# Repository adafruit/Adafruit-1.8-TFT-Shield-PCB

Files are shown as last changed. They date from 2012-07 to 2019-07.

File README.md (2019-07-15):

## Adafruit 1.8" 18-bit Color TFT Shield w/microSD and Joystick PCB

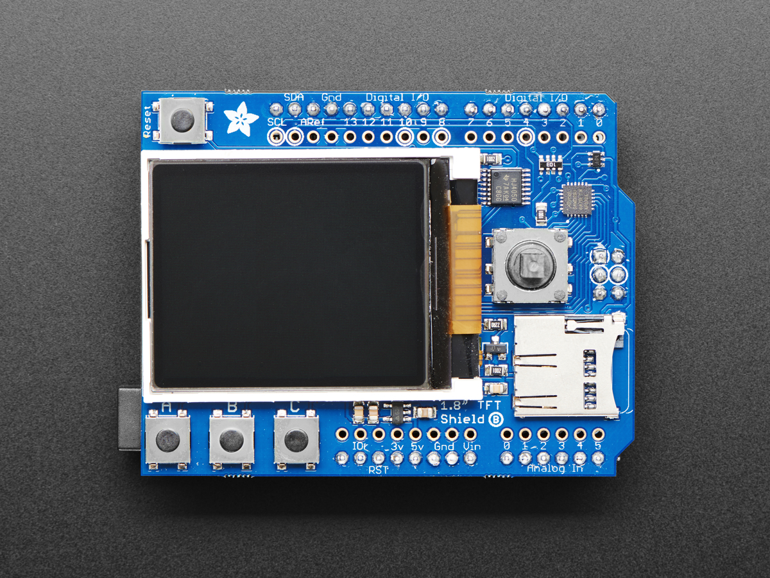
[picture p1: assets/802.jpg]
<a href="http://www.adafruit.com/products/802"><br/>
Click here to purchase one from the Adafruit shop</a>

PCB files for the Adafruit 1.8" 18-bit Color TFT Shield. Format is EagleCAD schematic and board layout
* https://www.adafruit.com/product/802

### Description

This lovely little shield is the best way to add a small, colorful and bright display to any project. We took our popular 1.8" TFT breakout board and remixed it into an Arduino shield complete with microSD card slot and a 5-way joystick navigation switch and three selection buttons! Since the display uses only 4 pins to communicate and has its own pixel-addressable frame buffer, it can be used easily to add a display & interface without exhausting the memory or pins.

New! We've updated this shield to be 'Arduino R3' format compatible so you can now use it with any and all Arduinos or Metros - including the Metro M0 or M4, Arduino Mega, Zero, etc. We also use Adafruit seesaw for the TFT backlight, TFT reset, and button inputs - you can query the buttons and joystick over I2C now, so only 2 pins are needed to communicate with all 8 switches.

The 1.8" display has 128x160 color pixels. Unlike the low cost "Nokia 6110" and similar LCD displays, which are CSTN type and thus have poor color and slow refresh, this display is a true TFT! The TFT driver (ST7735R) can display full 18-bit color (262,144 shades!).

The shield has the TFT display soldered on (it uses a delicate flex-circuit connector) as well as a ultra-low-dropout 3.3V regulator and a 3/5V level shifter so its safe to use with 3V or 5V Arduino compatibles. We also had some space left over so we placed a microSD card holder (so you can easily load full color bitmaps from a FAT16/FAT32 formatted microSD card), a 5-way navigation switch (left, right, up, down, select) and three tactile buttons marked A BC. The microSD card is not included, but you can pick one up here.

If you just want to display text, shapes, lines, pixels, etc the shield uses the SPI pins (SCK/MOSI/MISO), I2C pins (SDA & SCL) and digital #8. For the microSD card, you'll also give up Digital #4. This shield works with any Arduino UNO and compatibles, Mega, Zero, etc. If it's shield compatible, you're good to go.

### License

Adafruit invests time and resources providing this open source design, please support Adafruit and open-source hardware by purchasing products from [Adafruit](https://www.adafruit.com)!

Designed by Limor Fried/Ladyada for Adafruit Industries.

Creative Commons Attribution/Share-Alike, all text above must be included in any redistribution. See license.txt for additional details.

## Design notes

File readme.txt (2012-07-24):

Adafruit 1.8" 18-bit Color TFT Shield w/microSD and Joystick 

These are the Eagle CAD files for the Adafruit 1.8" 18-bit Color TFT Shield w/microSD and Joystick - for Arduino:
  ----> http://www.adafruit.com/products/802

Adafruit invests time and resources providing this open source design, please support Adafruit and open-source hardware by purchasing products from Adafruit!

This lovely little shield is the best way to add a small, colorful and bright display to any project. We took our popular 1.8" TFT breakout board and remixed it into an Arduino shield complete with microSD card slot and a 5-way joystick navigation switch (with a nice plastic knob)! Since the display uses only 4 pins to communicate and has its own pixel-addressable frame buffer, it can be used easily to add a display & interface without exhausting the memory or pins. 

All text above must be included in any redistribution

Designed by Limor Fried/Ladyada for Adafruit Industries.
Creative Commons Attribution/Share-Alike, all text above must be included in any redistribution

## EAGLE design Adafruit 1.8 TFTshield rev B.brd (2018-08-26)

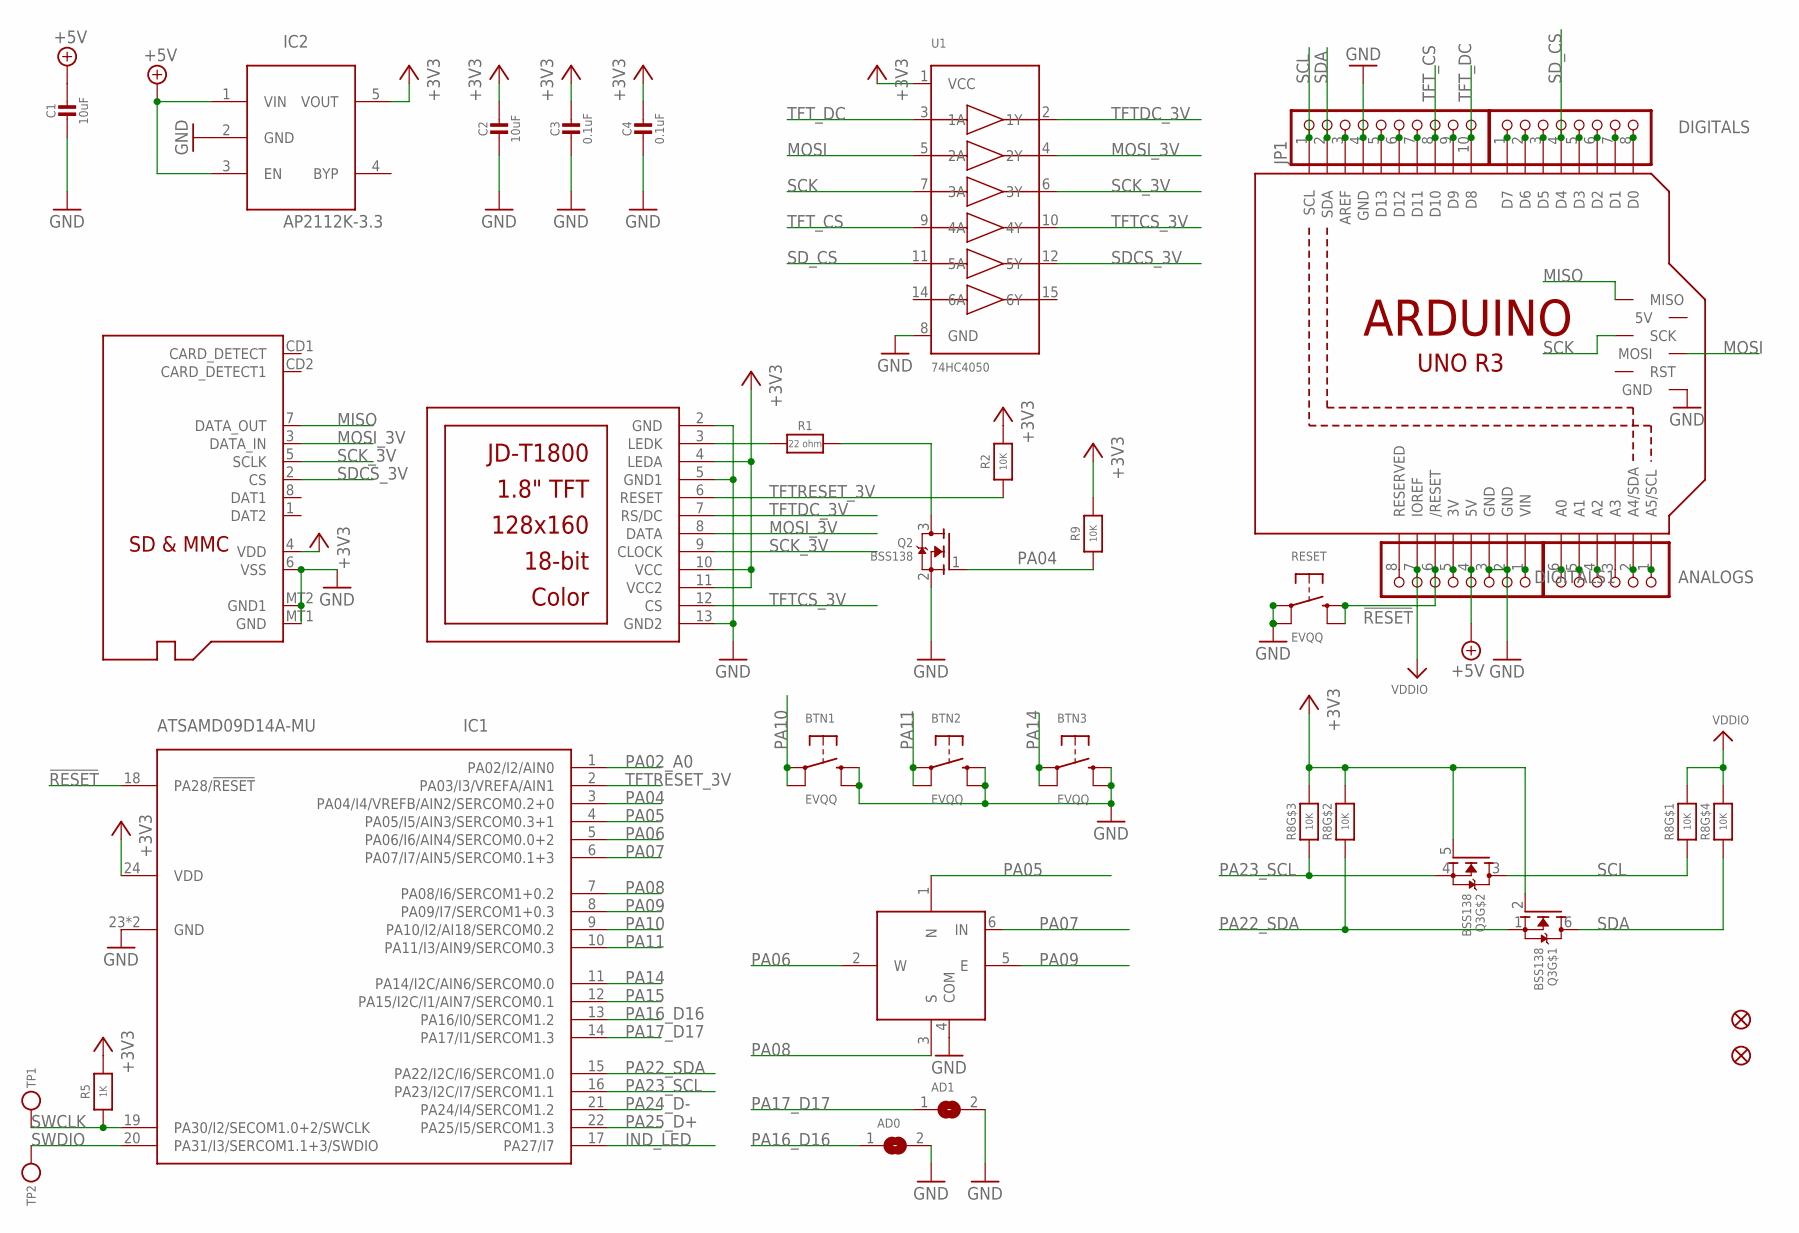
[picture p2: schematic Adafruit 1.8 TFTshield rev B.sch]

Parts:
AD0, AD1: SOLDERJUMPER; SOLDERJUMPER_ARROW_NOPASTE
ANALOGS: HEADER-1X6ROUND; 1X06_ROUND
BTN1, BTN2, BTN3: EVQQ; EVQ-Q2_SMALLER
C1, C2: 10uF; 0805-NO
C3, C4: 0.1uF; 0805-NO
DIGITALS, DIGITALS1: HEADER-1X8ROUND; 1X08_ROUND
FID1, FID3: FIDUCIAL_1MM
IC1: ATSAMD09D14A-MU; QFN24_4MM
IC2: AP2112K-3.3; SOT23-5L
JP1: HEADER-1X10ROUND; 1X10_ROUND
M1: ARDUINO_R3_ICSP; ARDUINOR3_ICSP
Q2: BSS138; SOT23-WIDE
Q3: BSS138; SOT363
R1: 22 ohm; 0805-NO
R2, R9: 10K; 0805-NO
R5: 1K; 0805-NO
R8: 10K; RESPACK_4X0603_NO
RESET: EVQQ; EVQ-Q2_SMALLER
SW1: NAVSWITCHSKQUABAUE010; SKQUBAE010
TP1, TP2: TESTPOINTROUND2MM; TESTPOINT_ROUND_2MM
U1: 74HC4050; TSSOP16
U$1: DISP_LCD_JDT1800; JD-T1800
U$3: MICROSD

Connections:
!RESET: DIGITALS1.6, IC1.18 (PA28/!RESET), M1.RESET (/RESET), RESET.B (S), RESET.B' (S1)
+3.3V: DIGITALS1.5, M1.3V
+3V3: C2.1, C3.1, C4.1, IC1.24 (VDD), IC2.5 (VOUT), Q3.2 (G), Q3.5 (G), R2.2, R5.2, R8.6 (2), R8.7 (2), R9.2, U1.1 (VCC), U$1.4 (LEDA), U$1.10 (VCC), U$1.11 (VCC2), U$3.4 (VDD)
+5V: C1.1, DIGITALS1.4, IC2.1 (VIN), IC2.3 (EN), M1.5V
A0: ANALOGS.6, M1.A0
A1: ANALOGS.5, M1.A1
A2: ANALOGS.4, M1.A2
A4: ANALOGS.2, M1.A4 (A4/SDA)
A5: ANALOGS.1, M1.A5 (A5/SCL)
AREF: JP1.3, M1.AREF
D0: DIGITALS.8, M1.D0
D1: DIGITALS.7, M1.D1
D2: DIGITALS.6, M1.D2
D3: DIGITALS.5, M1.D3
D5: DIGITALS.3, M1.D5
D6: DIGITALS.2, M1.D6
D7: DIGITALS.1, M1.D7
D9: JP1.9, M1.D9
GND: AD0.2, AD1.2, BTN1.B (S), BTN1.B' (S1), BTN2.B (S), BTN2.B' (S1), BTN3.B (S), BTN3.B' (S1), C1.2, C2.2, C3.2, C4.2, DIGITALS1.2, DIGITALS1.3, IC1.23 (GND), IC1.THERM (GND), IC2.2 (GND), JP1.4, M1.GND, M1.GND@1 (GND), M1.GND@2 (GND), M1.GND@3 (GND), Q2.2 (S), RESET.A, RESET.A' (P1), SW1.4 (COM), U1.8 (GND), U$1.2 (GND), U$1.5 (GND1), U$1.13 (GND2), U$3.6 (VSS), U$3.MT1 (GND), U$3.MT2 (GND1)
IND_LED: IC1.17 (PA27/I7)
MISO: M1.MISO, U$3.7 (DATA_OUT)
MOSI: M1.MOSI, U1.5 (2A)
MOSI_3V: U1.4 (2Y), U$1.8 (DATA), U$3.3 (DATA_IN)
unnamed: R1.1, U$1.3 (LEDK)
unnamed: Q2.3 (D), R1.2
unnamed: JP1.5, M1.D13
unnamed: JP1.6, M1.D12
unnamed: JP1.7, M1.D11
unnamed: ANALOGS.3, M1.A3
unnamed: DIGITALS1.8, M1.RESERVED
PA02_A0: IC1.1 (PA02/I2/AIN0)
PA04: IC1.3 (PA04/I4/VREFB/AIN2/SERCOM0.2+0), Q2.1 (G), R9.1
PA05: IC1.4 (PA05/I5/AIN3/SERCOM0.3+1), SW1.1 (N)
PA06: IC1.5 (PA06/I6/AIN4/SERCOM0.0+2), SW1.2 (W)
PA07: IC1.6 (PA07/I7/AIN5/SERCOM0.1+3), SW1.6 (IN)
PA08: IC1.7 (PA08/I6/SERCOM1+0.2), SW1.3 (S)
PA09: IC1.8 (PA09/I7/SERCOM1+0.3), SW1.5 (E)
PA10: BTN1.A, BTN1.A' (P1), IC1.9 (PA10/I2/AI18/SERCOM0.2)
PA11: BTN2.A, BTN2.A' (P1), IC1.10 (PA11/I3/AIN9/SERCOM0.3)
PA14: BTN3.A, BTN3.A' (P1), IC1.11 (PA14/I2C/AIN6/SERCOM0.0)
PA15: IC1.12 (PA15/I2C/I1/AIN7/SERCOM0.1)
PA16_D16: AD0.1, IC1.13 (PA16/I0/SERCOM1.2)
PA17_D17: AD1.1, IC1.14 (PA17/I1/SERCOM1.3)
PA22_SDA: IC1.15 (PA22/I2C/I6/SERCOM1.0), Q3.1 (S), R8.2 (1)
PA23_SCL: IC1.16 (PA23/I2C/I7/SERCOM1.1), Q3.4 (S), R8.3 (1)
PA24_D-: IC1.21 (PA24/I4/SERCOM1.2)
PA25_D+: IC1.22 (PA25/I5/SERCOM1.3)
SCK: M1.SCK, U1.7 (3A)
SCK_3V: U1.6 (3Y), U$1.9 (CLOCK), U$3.5 (SCLK)
SCL: JP1.1, M1.SCL, Q3.3 (D), R8.1
SDA: JP1.2, M1.SDA, Q3.6 (D), R8.4 (1)
SDCS_3V: U1.12 (5Y), U$3.2 (CS)
SD_CS: DIGITALS.4, M1.D4, U1.11 (5A)
SWCLK: IC1.19 (PA30/I2/SECOM1.0+2/SWCLK), R5.1, TP1.P$1
SWDIO: IC1.20 (PA31/I3/SERCOM1.1+3/SWDIO), TP2.P$1
TFTCS_3V: U1.10 (4Y), U$1.12 (CS)
TFTDC_3V: U1.2 (1Y), U$1.7 (RS/DC)
TFTRESET_3V: IC1.2 (PA03/I3/VREFA/AIN1), R2.1, U$1.6 (RESET)
TFT_CS: JP1.8, M1.D10, U1.9 (4A)
TFT_DC: JP1.10, M1.D8, U1.3 (1A)
VDDIO: DIGITALS1.7, M1.IOREF, R8.5 (2), R8.8 (2)
VIN: DIGITALS1.1, M1.VIN

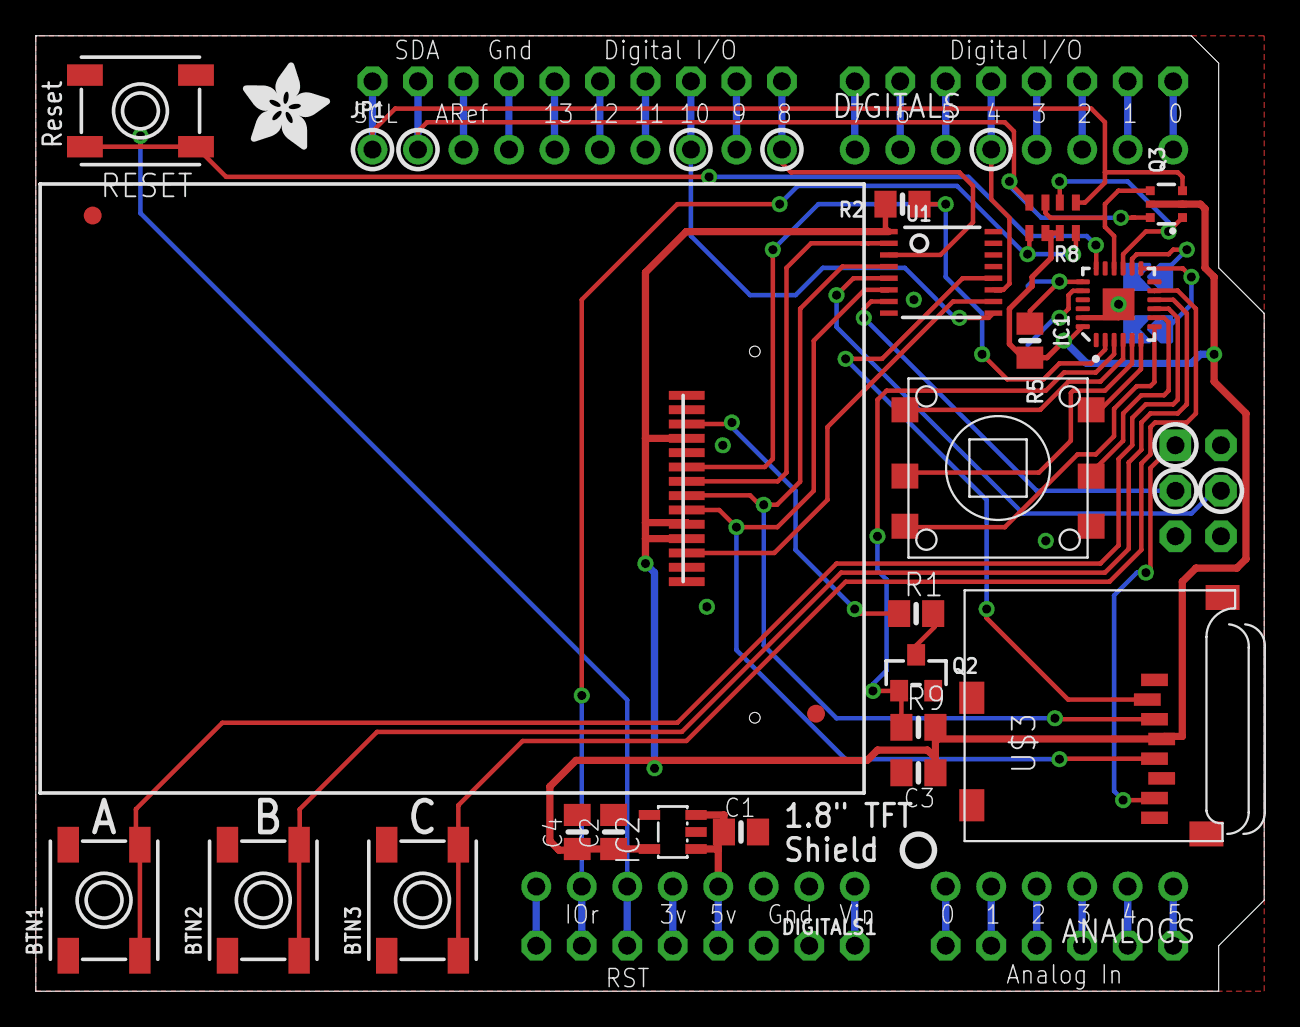
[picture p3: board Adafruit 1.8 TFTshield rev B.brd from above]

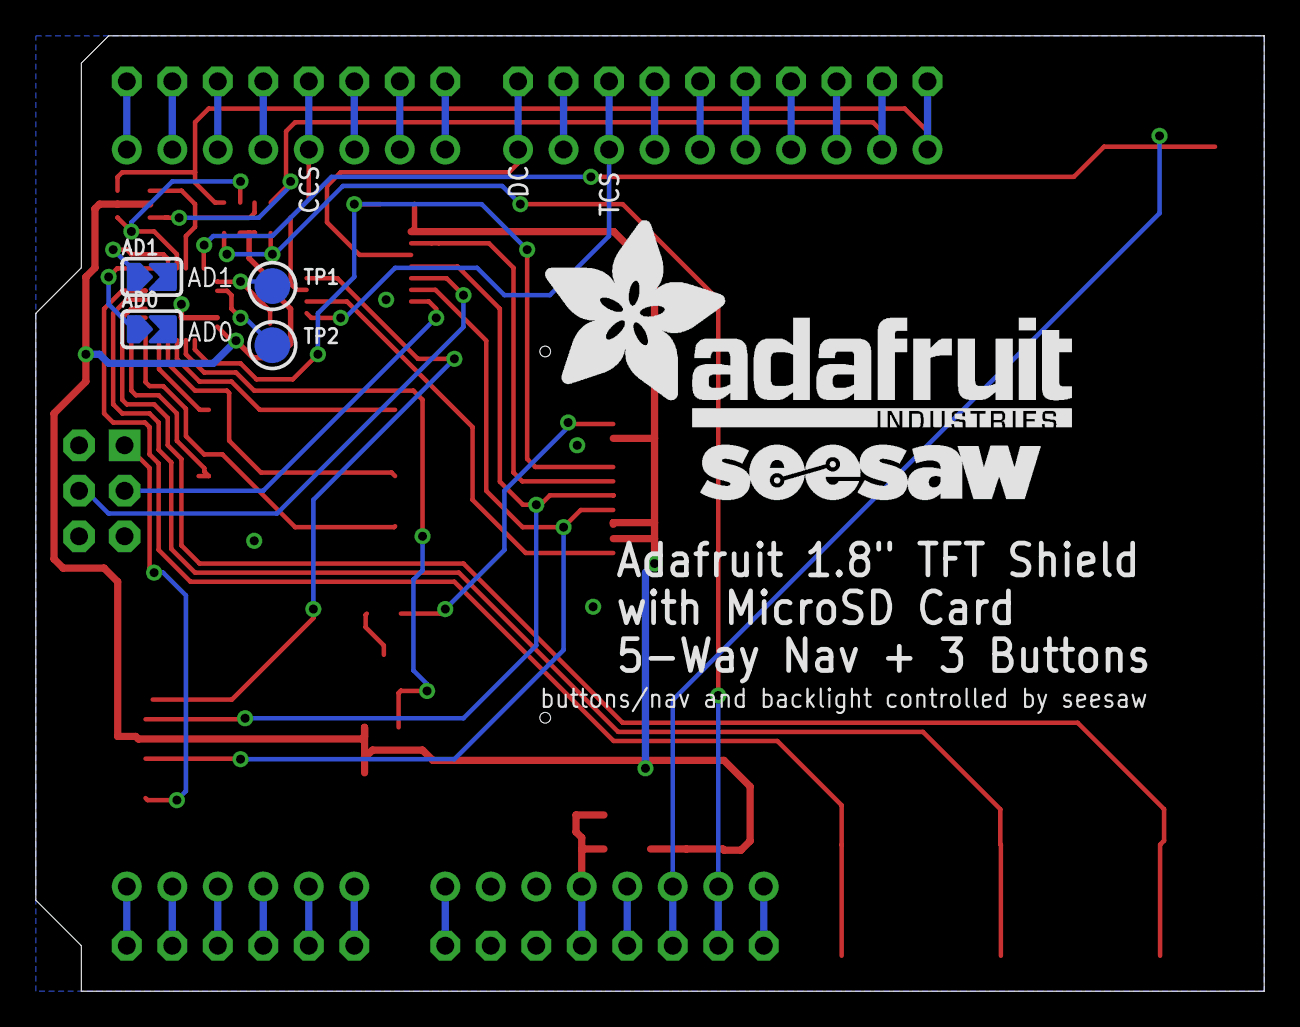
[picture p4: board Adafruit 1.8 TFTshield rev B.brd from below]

Board: 2 copper layers, 68.6 x 53.3 mm, 36 parts (6 on the bottom side), 57 nets.

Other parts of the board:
U$5: ADAFRUIT_TEXT_30MM
U$7: ADAFRUIT_5MM
U$8: SEESAW_LOGO
U$9: PCBFEAT-REV-040
